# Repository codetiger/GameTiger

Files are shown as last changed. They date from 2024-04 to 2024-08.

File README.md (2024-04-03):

<p align="center">
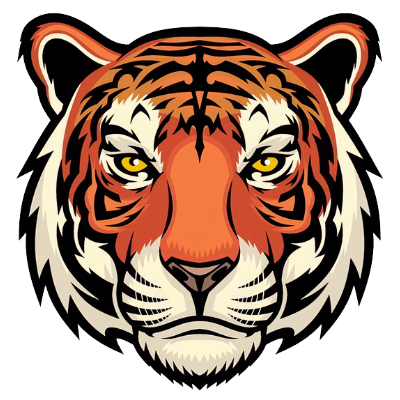
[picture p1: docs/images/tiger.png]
    
</p>
<p align="center">
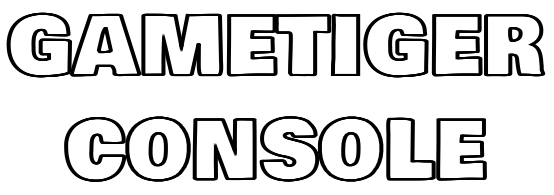
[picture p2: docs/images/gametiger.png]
    </p>
</p>

## About GameTiger Console
A retro-themed gaming console, crafted and tailored exclusively for educational enjoyment. The console boasts a custom-designed printed circuit board (PCB), meticulously created entirely from the ground up, and is centered around the remarkable RP2040 MCU chip. The primary objective of this endeavor is to maintain complete openness, facilitating the exploration of electronic PCB design and the establishment of a platform that fosters the creation of games and emulators on microcontrollers.

<div style="display: flex; justify-content: space-between;">
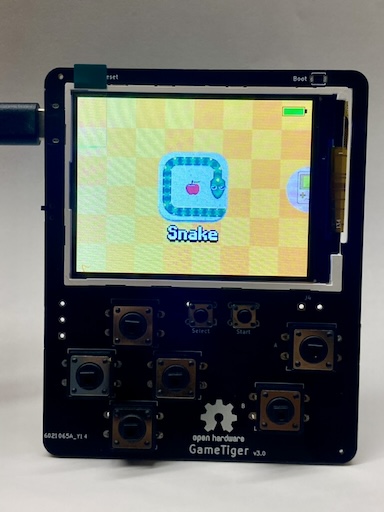
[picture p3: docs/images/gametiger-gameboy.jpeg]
GameTiger Console
    
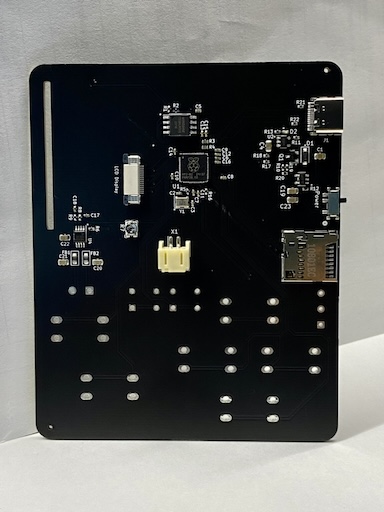
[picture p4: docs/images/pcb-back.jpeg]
    
</div>

## Games
| | |
|---|---|
| Snake | 2048 |
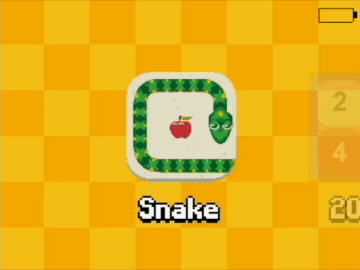
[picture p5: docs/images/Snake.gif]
Snake Game GameTiger Console
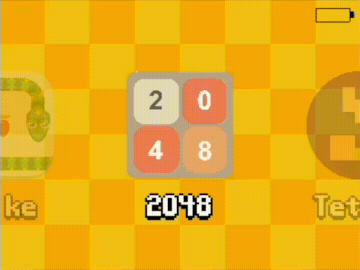
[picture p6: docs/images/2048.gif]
2048 Game GameTiger Console
|  |  
| Tetris | Minesweeper |
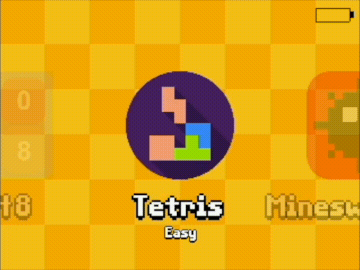
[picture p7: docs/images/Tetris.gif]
Tetris Game GameTiger Console
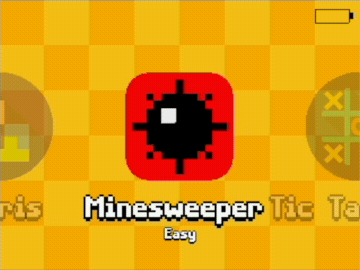
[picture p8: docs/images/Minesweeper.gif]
Minesweeper Game GameTiger Console
|  | 
| Tic Tac Toe | Ninja Frog |
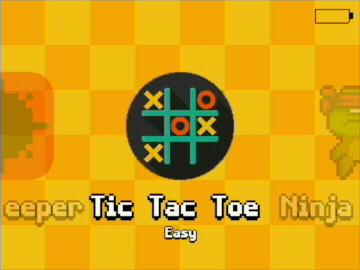
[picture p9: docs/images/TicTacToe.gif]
Tic Tac Toe Game GameTiger Console
|  | Ninja Frog Game GameTiger Console

## Software
The software is constructed using the Pico C++ SDK, incorporating essential hardware interfacing functionalities. As an illustration, the well-known Snake game is already available. The following modules are currently available and are continually being developed.

* Operating System Drivers
    * Display driver
    * Button interrupts
    * Battery management system driver
* Framebuffer Library
    * Supports transparency
    * Streaming to display memory using DMA
    * Draw primitives (Line, Rect, Fill Rect)
    * Supports drawing images with alpha channel
* Sprite sheet 
    * Support for sprite sheet 
    * Basic tilemap support
* Font system based on Sprite sheet
* Menu system
    * Games
    * Hardware config
        * Display brightness
        * Display sleep time after inactivity

The software is well optimised to achieve a target of 30 frames per second. The Snake game achieves more than 44 FPS on a default settings without overclocking. 

Hardware V3:

GameTiger Console (https://youtu.be/j1MeKHOfR0Q)

Hardware V2:

GameTiger Console (https://youtu.be/e6qAUd7l6A4)

Hardware V1:

GameTiger Console (https://youtu.be/edIZAm9zVC8)

## Build your favourite games
If you're looking to contribute to the project by developing your own games for the GameTiger console, please refer to our developer guide for detailed instructions.
[Developer's Guide](docs/dev_guide.md)

## To Do
* Add more games
* Design Case in CAD software for 3d printing

## License
The entire project is open-sourced software licensed under the MIT license.

## References
* [Hardware Design with RP2040](https://datasheets.raspberrypi.com/rp2040/hardware-design-with-rp2040.pdf)
* [Minimal RP2040 Board](http://www.technoblogy.com/show?3U75)
* [HAGL Graphics Library](https://github.com/tuupola/hagl)
* [PCB Design for RP2040 youtube video](https://www.youtube.com/watch?v=kcwvuwetgEQ)

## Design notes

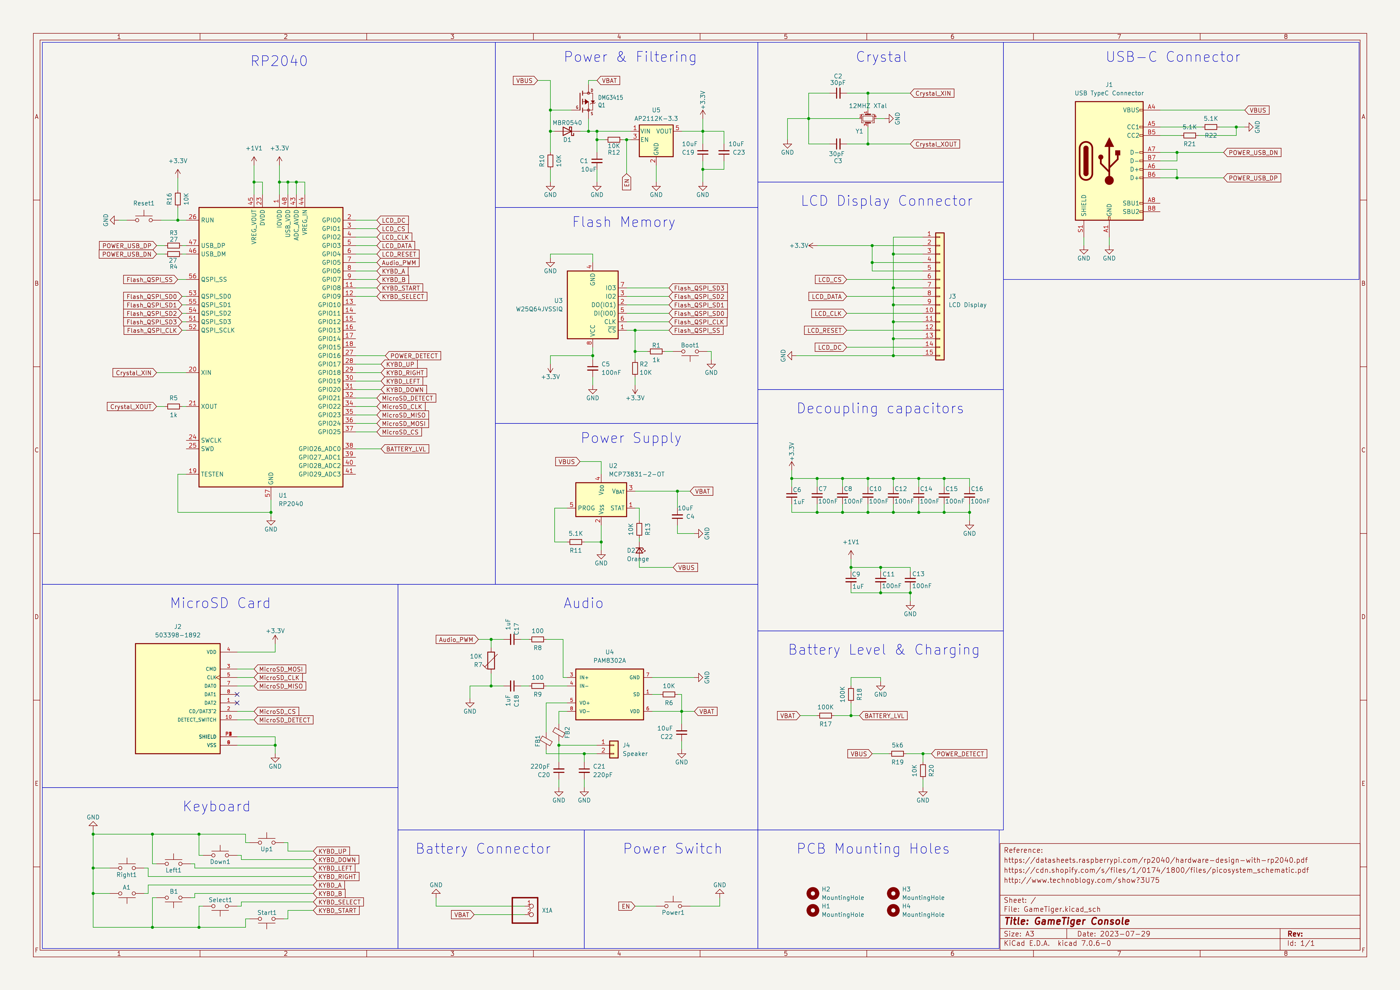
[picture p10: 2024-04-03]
PCB/GameTigerSchematic.png

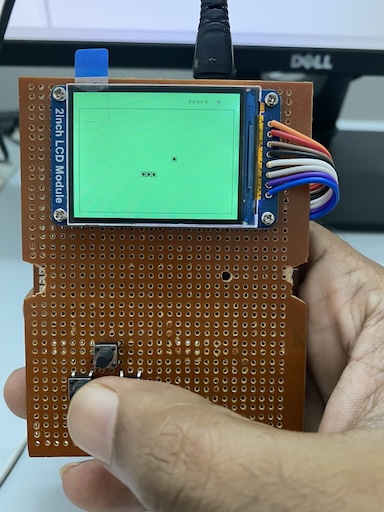
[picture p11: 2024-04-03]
docs/images/8-feb-2022.jpeg

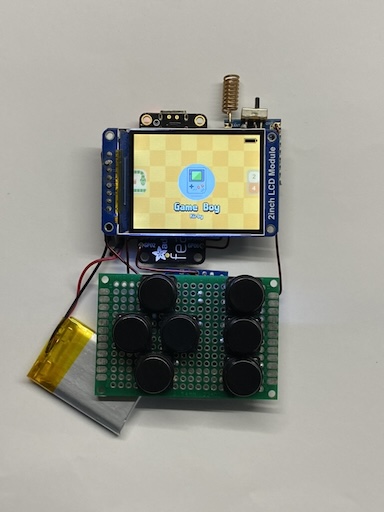
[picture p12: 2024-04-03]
docs/images/13-may-2023.jpeg

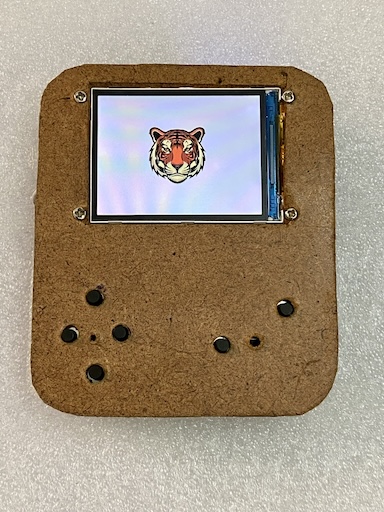
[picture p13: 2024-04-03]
docs/images/22-feb-2022.jpeg

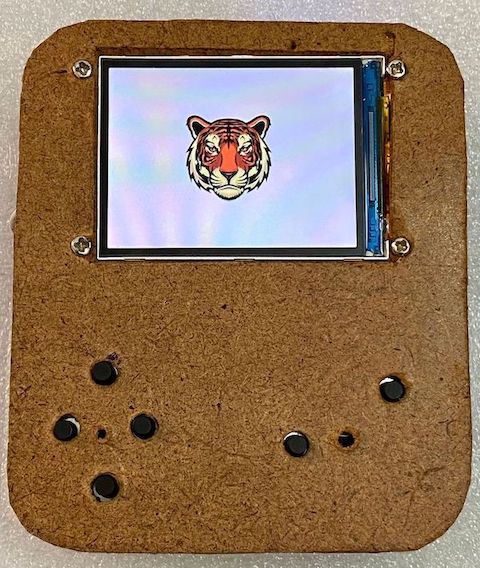
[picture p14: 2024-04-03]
docs/images/gametiger.jpg

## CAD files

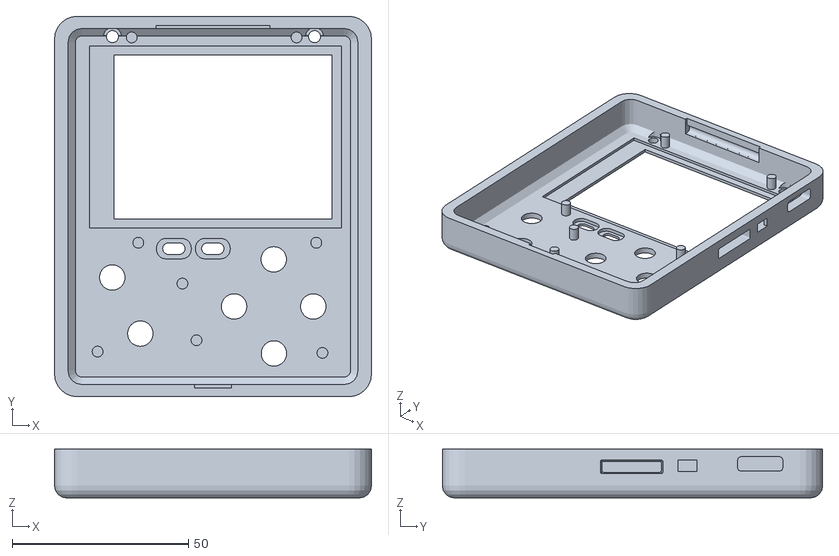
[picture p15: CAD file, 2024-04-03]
Case/GameTigerCaseFront.stl
90.0 x 108.0 x 13.9

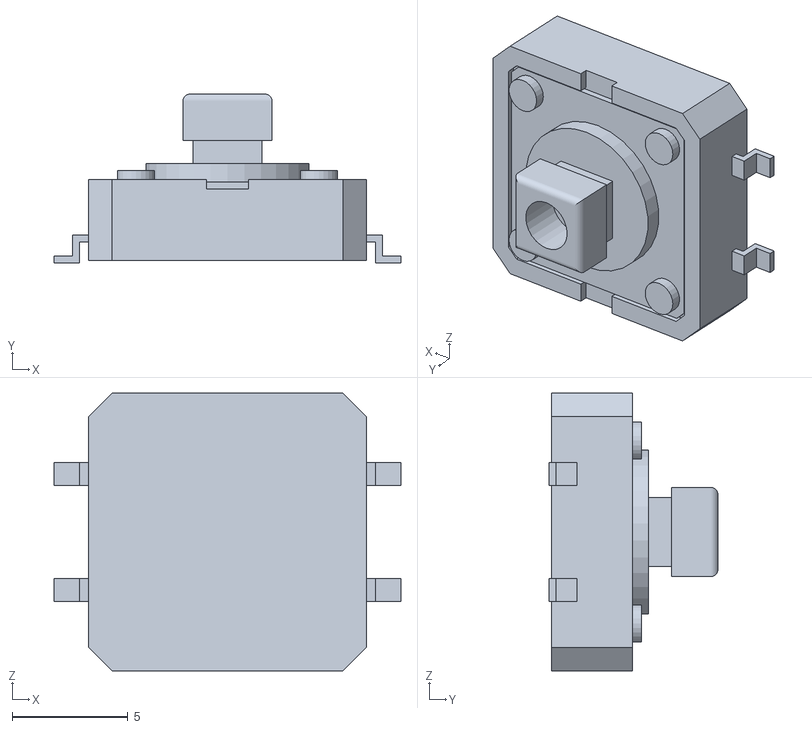
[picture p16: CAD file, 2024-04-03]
PCB/144187057-53-b3fs-4052p/b3fs-4052p.obj
15.0 x 7.30 x 12.0

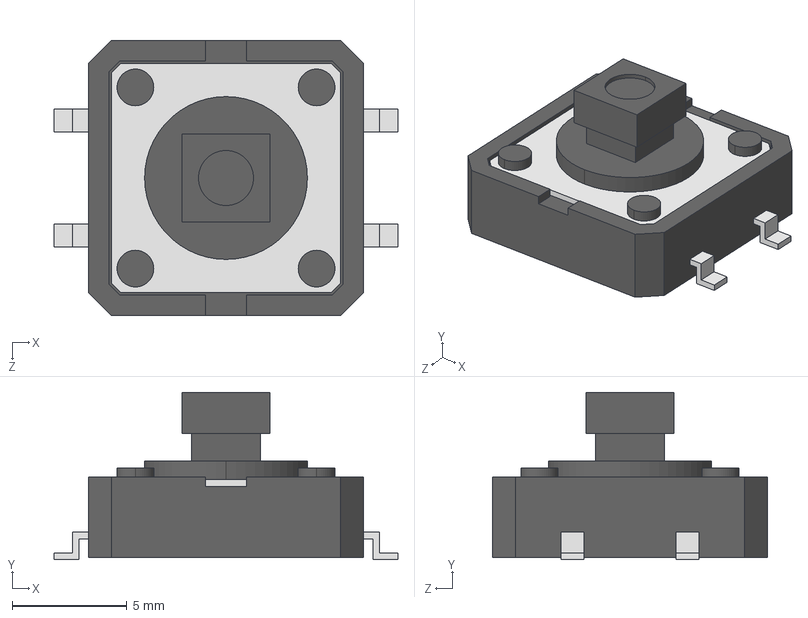
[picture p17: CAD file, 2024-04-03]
PCB/B3FS-4052P--3DModel-STEP-273799.STEP
15.0 x 7.30 x 12.0 mm

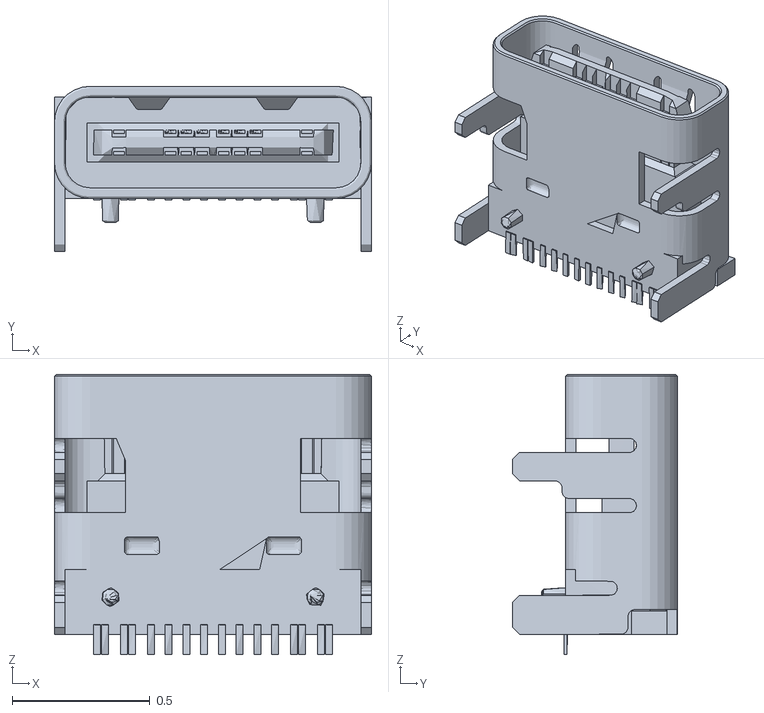
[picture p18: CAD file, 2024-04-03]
PCB/GT-USB-7010ASV/OBJ_NEW_PCB.obj
1.15 x 0.599 x 1.02

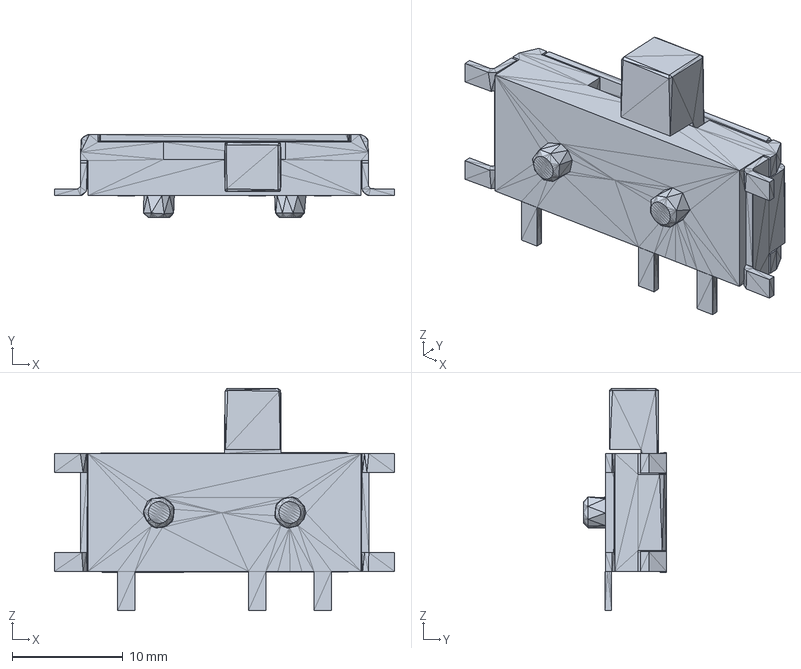
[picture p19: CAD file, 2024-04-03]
PCB/MK-12C02-G020/MK-12C02-G020.stp
30.7 x 7.48 x 20.1 mm
STEP translator 7.5 1.1
STEP translator 7.5 1.2

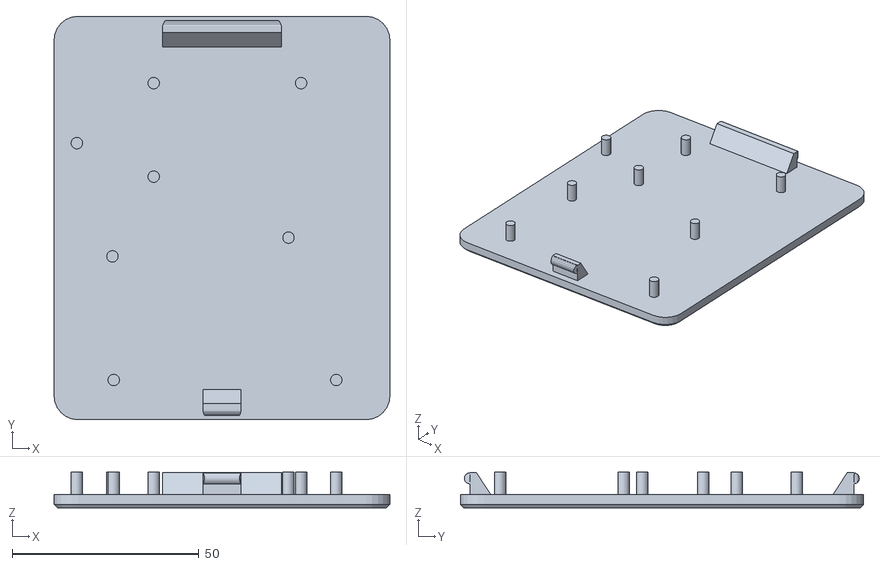
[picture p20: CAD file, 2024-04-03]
Case/GameTigerCaseBack.stl
89.9 x 108.0 x 9.52

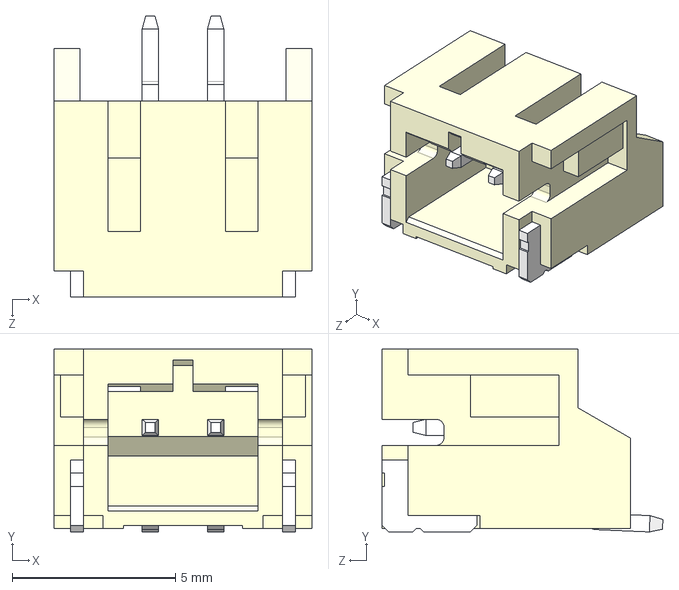
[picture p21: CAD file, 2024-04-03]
PCB/S2B-PH-SM4-TB(LF)(SN)--3DModel-STEP-56544.STEP
7.90 x 5.60 x 8.60 mm

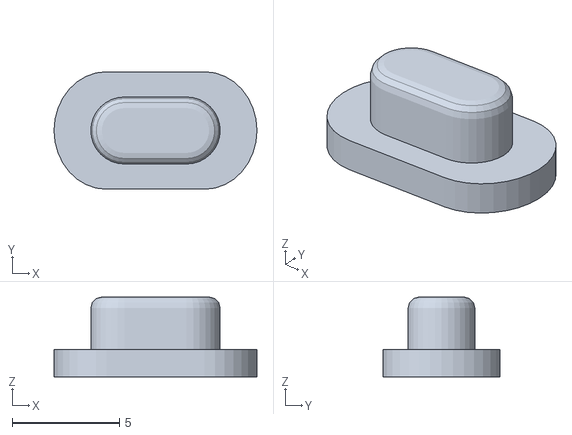
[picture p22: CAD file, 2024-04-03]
Case/GameTigerButtonSelect.stl
9.45 x 5.47 x 3.72

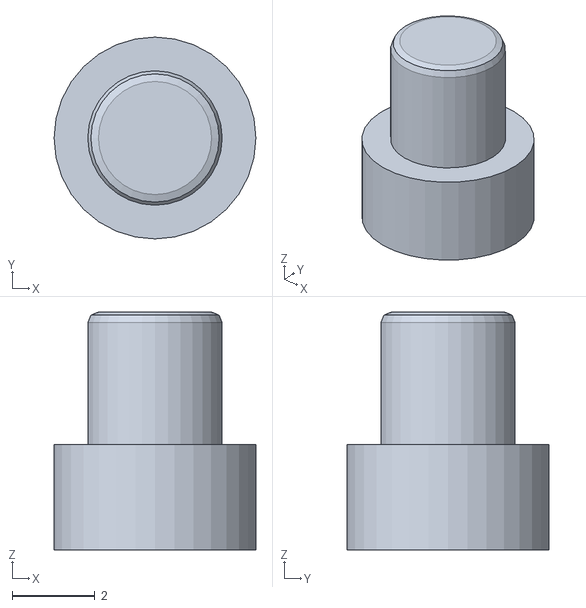
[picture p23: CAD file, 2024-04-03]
Case/GameTigerButtonBoot.stl
4.88 x 4.88 x 5.76

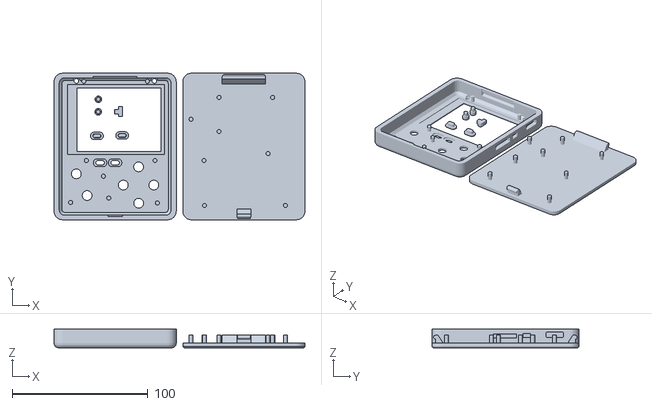
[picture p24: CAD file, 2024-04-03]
Case/GameTigerCase.stl
184.7 x 108.0 x 13.9

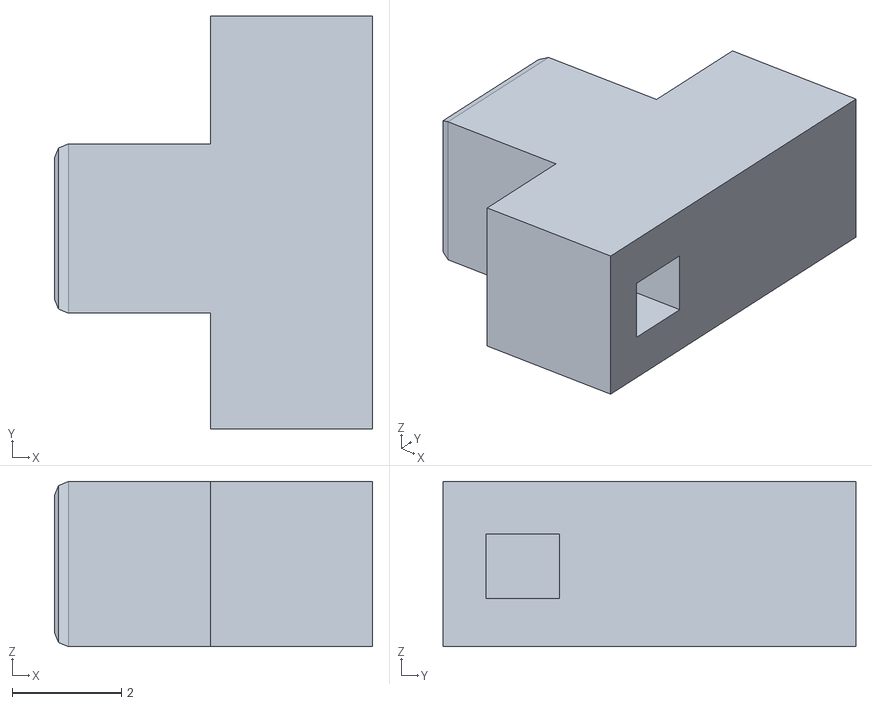
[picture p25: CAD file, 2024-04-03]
Case/GameTigerButtonPower.stl
5.82 x 7.55 x 3.02

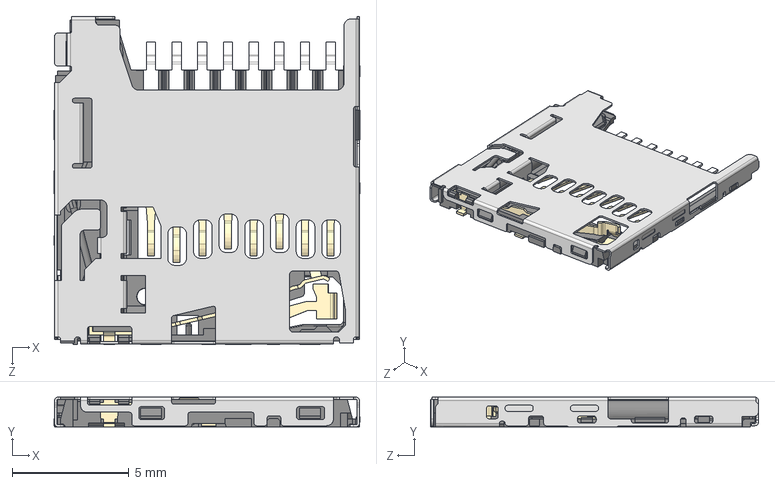
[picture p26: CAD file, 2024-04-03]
PCB/503398-1892/503398-1892.step
13.1 x 1.28 x 14.1 mm

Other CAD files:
Case/GameTigerButtonReset.stl
Case/GameTigerButtonStart.stl
Case/GameTigerCase.blend
PCB/GT-USB-7010ASV/GT-USB-7010ASV.blend

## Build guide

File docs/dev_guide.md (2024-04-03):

# Developer's Guide

This page contains details on setting up the development environment  for writing your own software for GameTiger console

## Building the firmware

First install required packages
```bash
sudo apt-get update
sudo apt-get install  git cmake build-essential gcc-arm-none-eabi libnewlib-arm-none-eabi libstdc++-arm-none-eabi-newlib
```

Clone the main repo
```bash
git clone https://github.com/codetiger/GameTiger-Console
```

Clone *pico-sdk* and *pico-extras* repository, since we will need them for compiling our code

```bash
git clone -b master --recurse-submodules https://github.com/codetiger/pico-sdk
git clone -b master --recurse-submodules https://github.com/raspberrypi/pico-extras
```

Set required environment variables (make sure to use proper paths depending upon your setup)

```bash
export PICO_SDK_PATH=/workspace/pico-sdk
export PICO_TOOLCHAIN_PATH=/usr
export PICO_EXTRAS_PATH=/workspace/pico-extras
```

Now let us compile the software for GameTiger console

```bash
cd GameTiger-Console
cmake .
make
```

On successful completion, you should see something similar to below output:

```bash
[ 97%] Performing build step for 'PioasmBuild'
[ 10%] Building CXX object CMakeFiles/pioasm.dir/main.cpp.o
[ 20%] Building CXX object CMakeFiles/pioasm.dir/pio_assembler.cpp.o
[ 30%] Building CXX object CMakeFiles/pioasm.dir/pio_disassembler.cpp.o
[ 40%] Building CXX object CMakeFiles/pioasm.dir/gen/lexer.cpp.o
[ 50%] Building CXX object CMakeFiles/pioasm.dir/gen/parser.cpp.o
[ 60%] Building CXX object CMakeFiles/pioasm.dir/c_sdk_output.cpp.o
[ 70%] Building CXX object CMakeFiles/pioasm.dir/python_output.cpp.o
[ 80%] Building CXX object CMakeFiles/pioasm.dir/hex_output.cpp.o
[ 90%] Building CXX object CMakeFiles/pioasm.dir/ada_output.cpp.o
[100%] Linking CXX executable pioasm
[100%] Built target pioasm
[ 98%] No install step for 'PioasmBuild'
[100%] Completed 'PioasmBuild'
[100%] Built target PioasmBuild
```

Once the compilation is successful, a firmware file called '*GameTiger.uf2*' should be generated in the '*GameTiger-Console*' folder.
Power on the console by holding the *boot* button and copy the '*GameTiger.uf2*' to the device.

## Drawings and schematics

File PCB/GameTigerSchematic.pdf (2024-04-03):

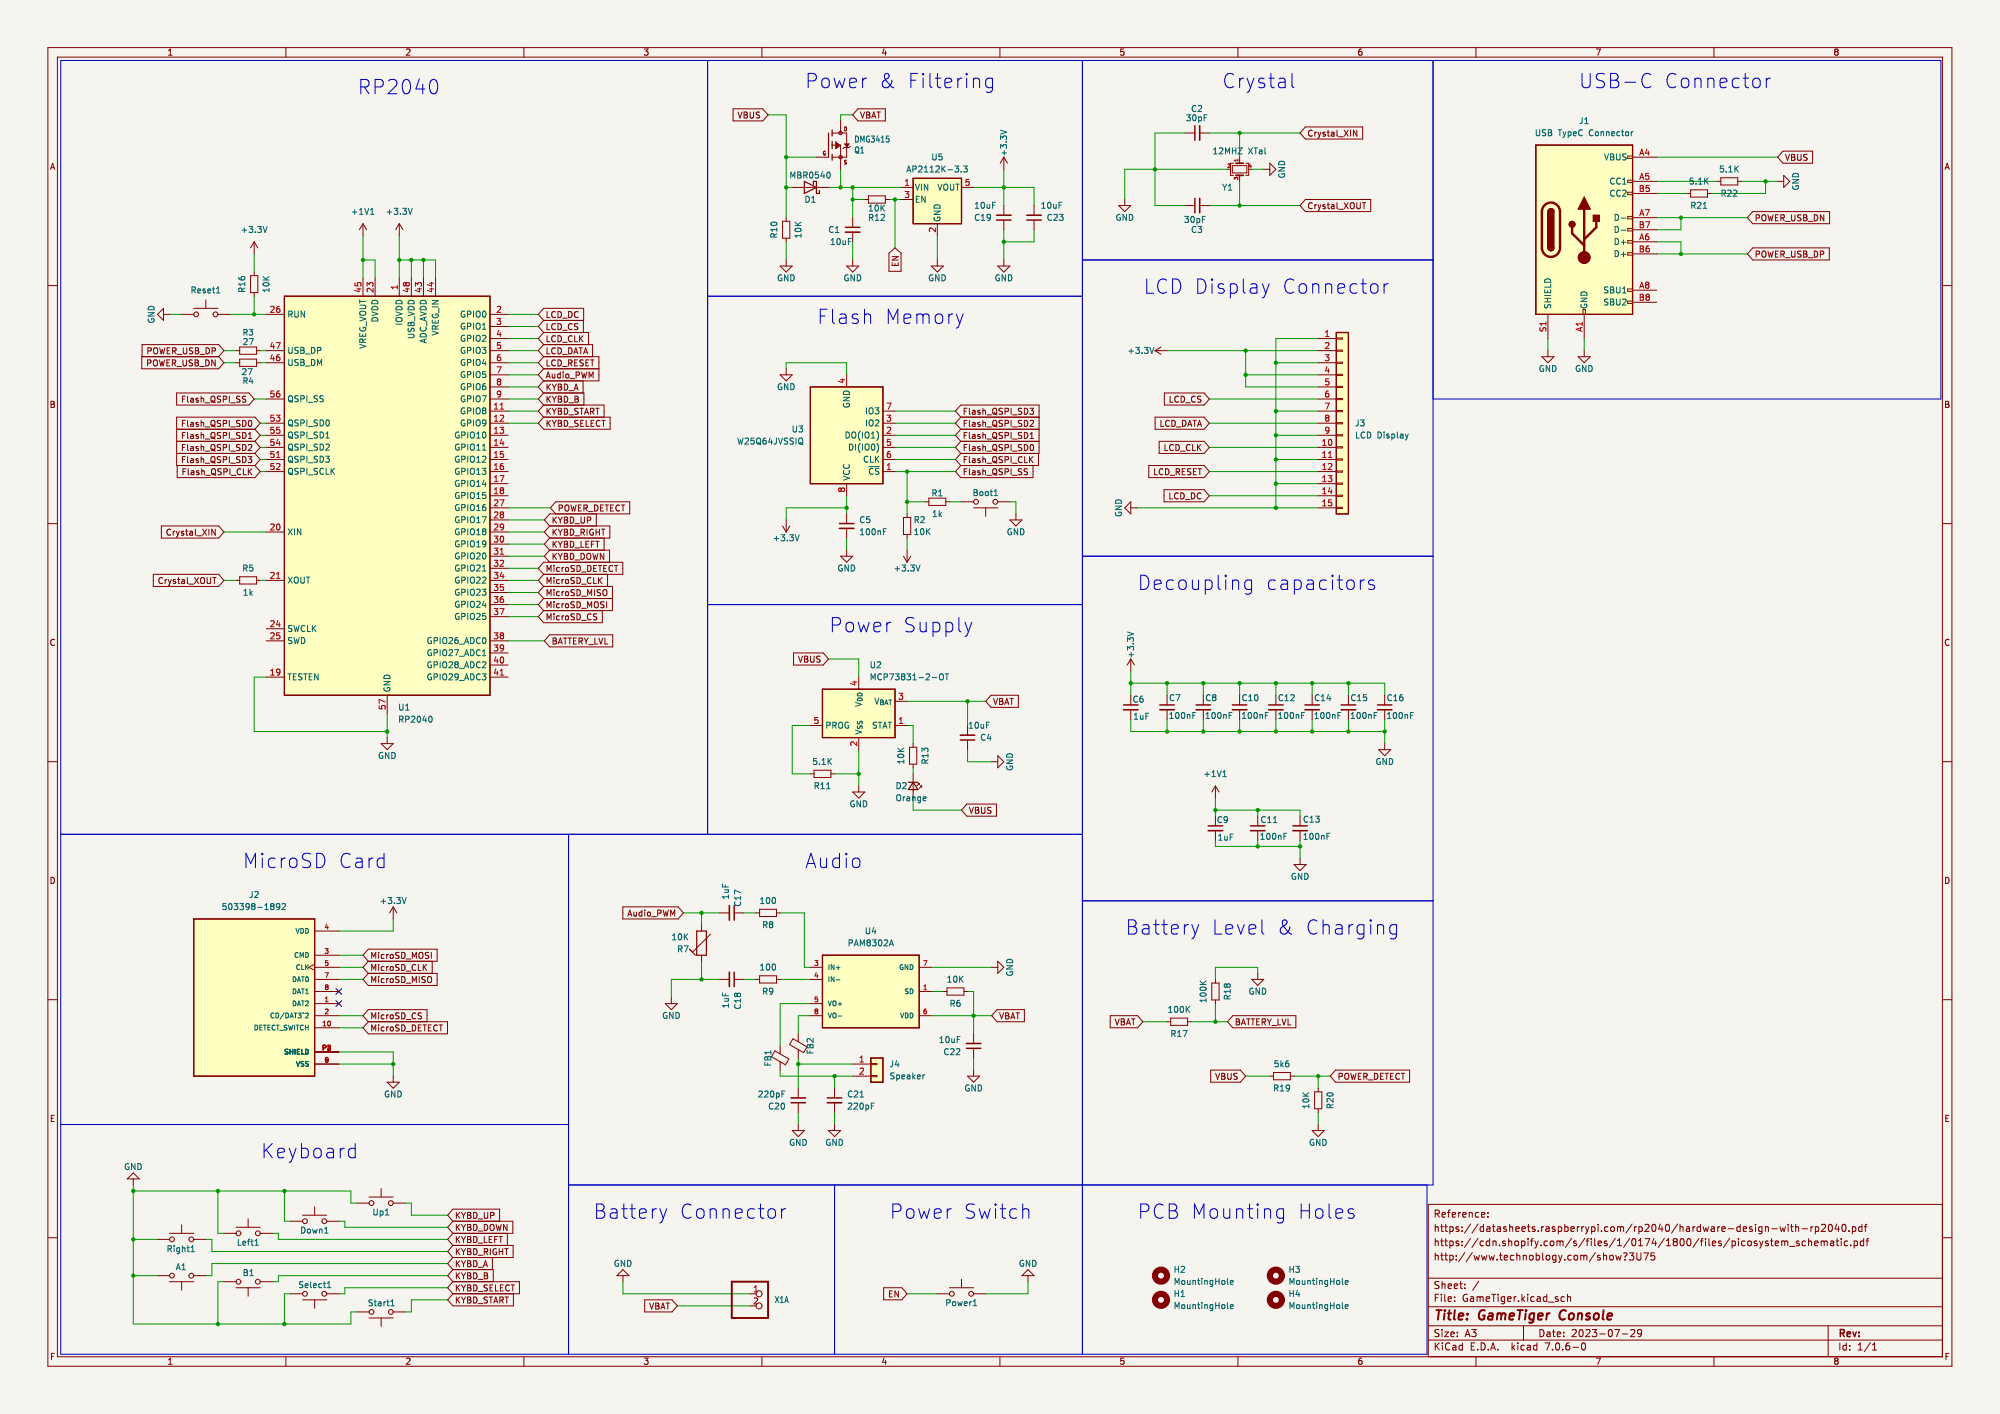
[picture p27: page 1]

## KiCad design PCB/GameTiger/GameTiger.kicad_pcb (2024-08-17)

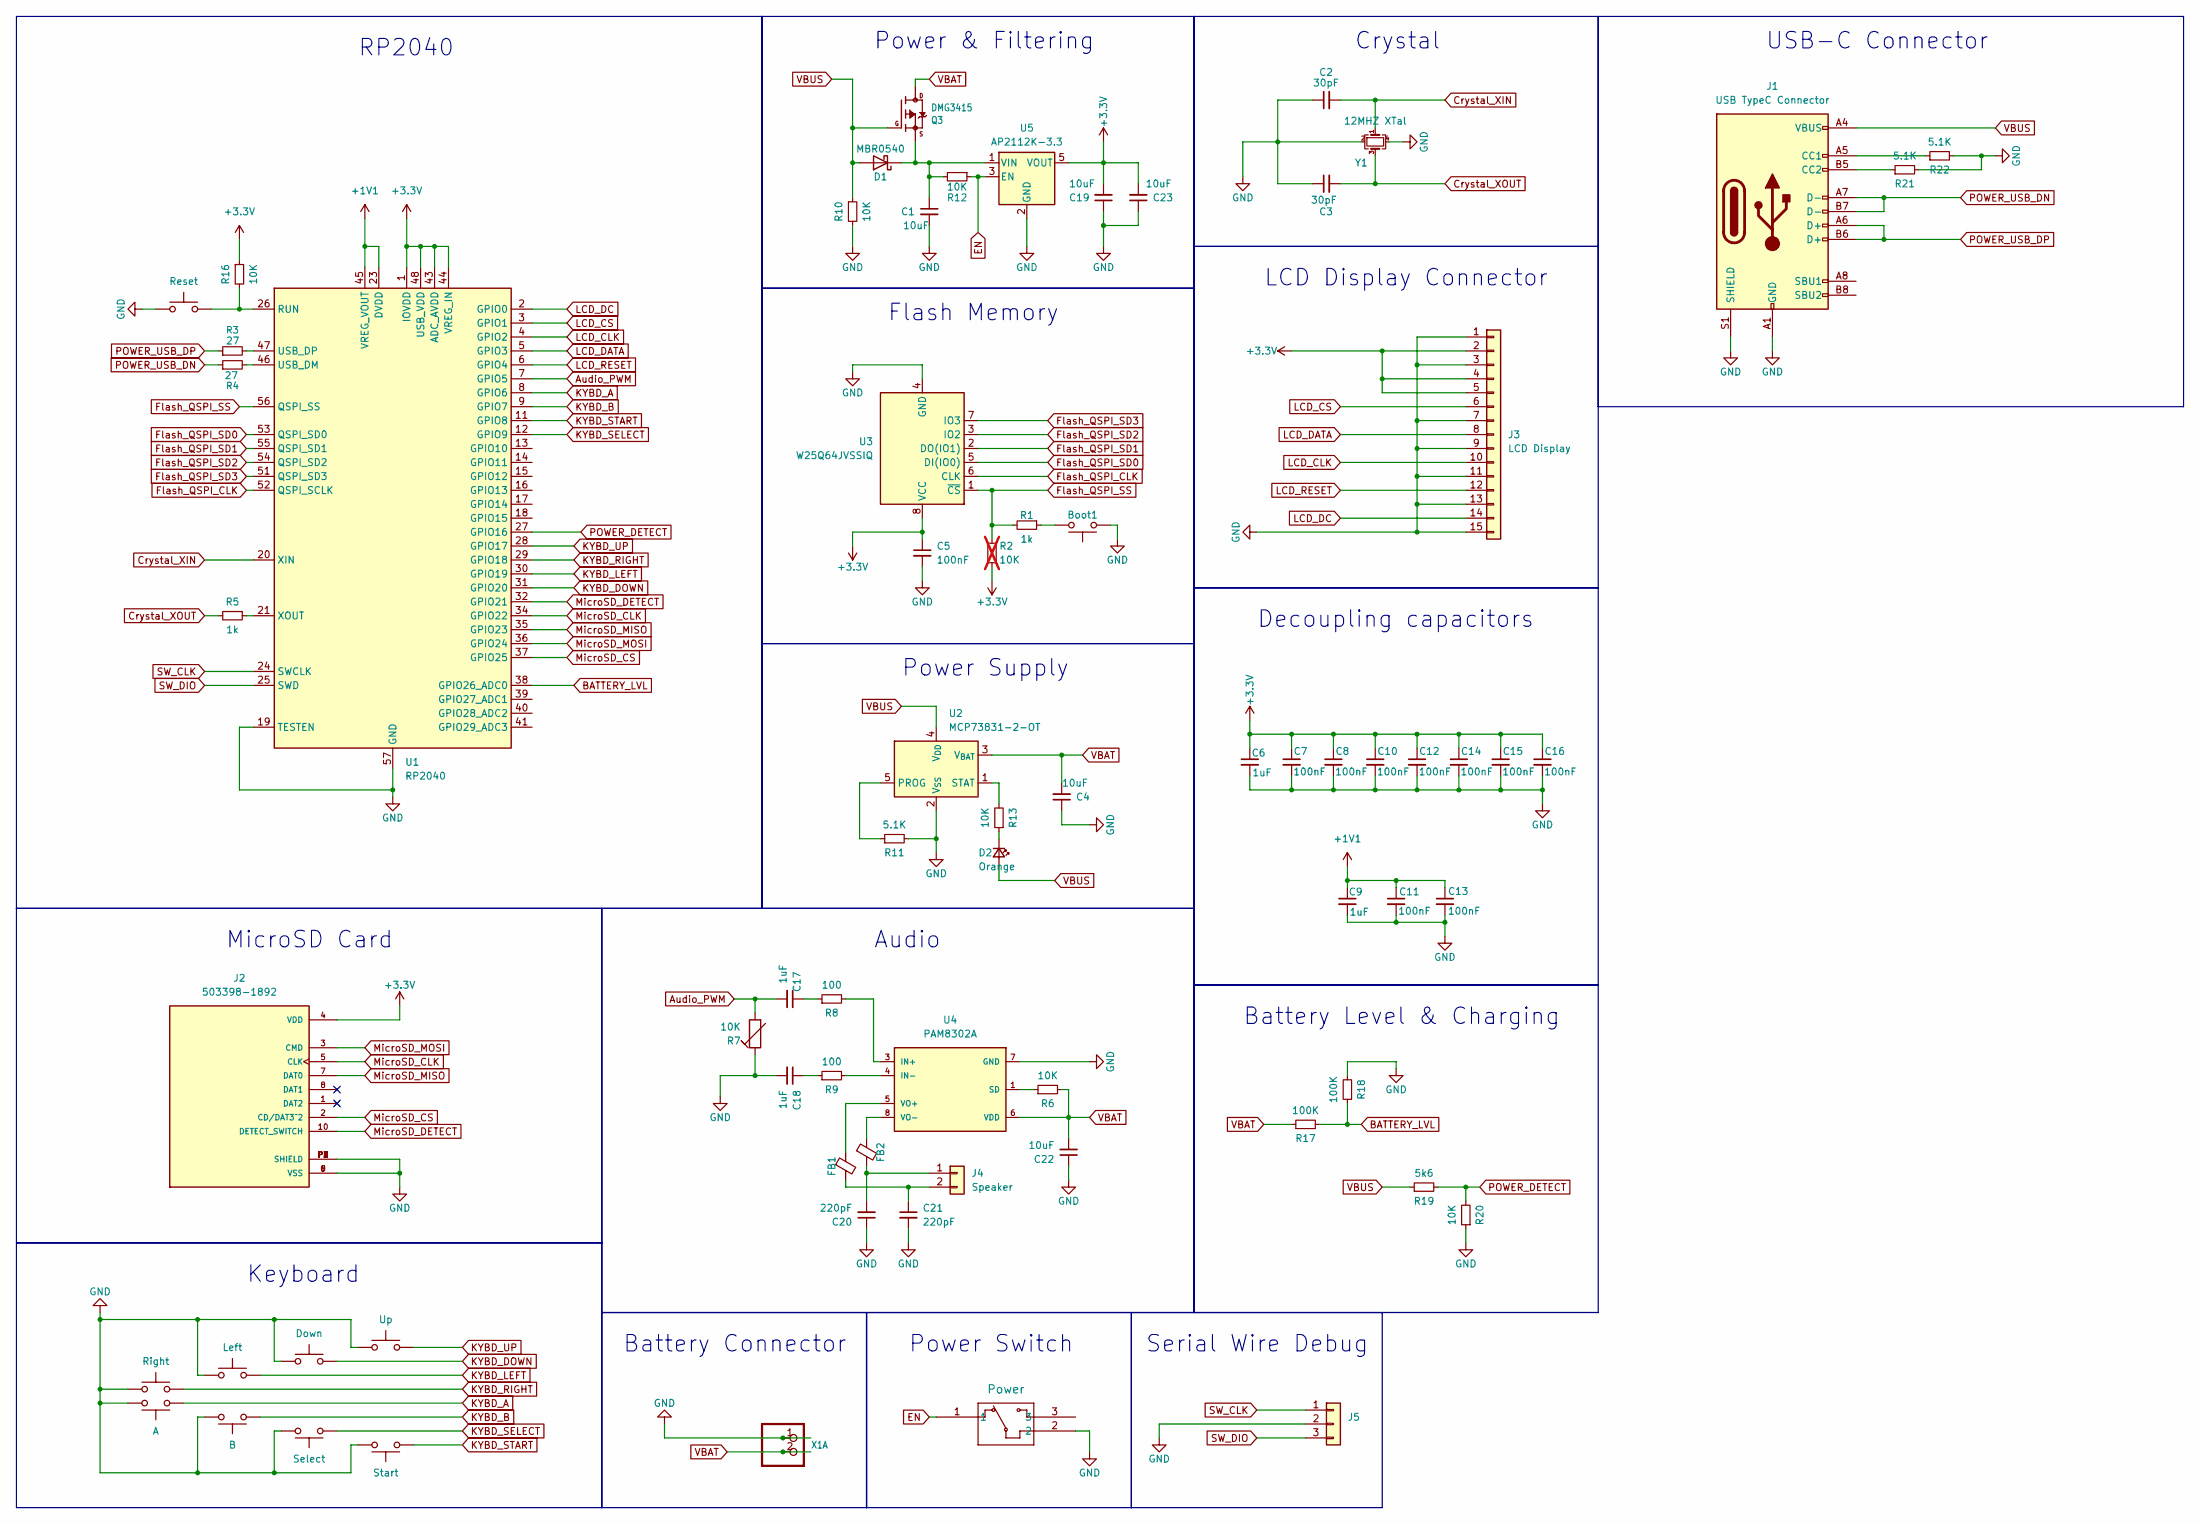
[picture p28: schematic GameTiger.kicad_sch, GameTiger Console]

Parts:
A1: A; SW_PUSH-12mm_3DModel; LCSC C411882
B1: B; SW_PUSH-12mm_3DModel; LCSC C411882
Boot1: Boot; SW_SPST_B3U-1000P; Mfr.Part # B3U-1000P; LCSC C231329
C1, C4, C19, C22, C23: 10uF; C_0805_2012Metric; LCSC C15850
C2, C3: 30pF; C_0402_1005Metric; LCSC C1570
C5, C7, C8, C10, C11, C12, C13, C14, C15, C16: 100nF; C_0402_1005Metric; LCSC C1525
C6, C9, C17, C18: 1uF; C_0402_1005Metric; LCSC C52923
C20, C21: 220pF; C_0805_2012Metric; LCSC C107145
D1: MBR0540; D_SOD-123; Manuf. Part # MBR0540; LCSC C116159
D2: Orange; LED_0402_1005Metric; LCSC C965791
Down1: Down; SW_PUSH-12mm_3DModel; LCSC C411882
FB1, FB2: FerriteBead_Small; Ferrite_0805_2012Metric; Manuf. Part # BLM21BD102SN1D; LCSC C85835
J1: USB TypeC Connector; USB_C_Receptacle_HRO_TYPE-C-31-M-12; Manuf. Part # GT-USB-7010ASV; LCSC C2988369
J2: 503398-1892; MOLEX_503398-1892; Manuf. Part # 5033981892; LCSC C428492
J3: LCD Display; TE_1-1734839-5_1x15-1MP_P0.5mm_Horizontal; Manuf. Part # 1-1734839-5; LCSC C262209
J4: Speaker; SolderWire-0.5sqmm_1x02_P4.6mm_D0.9mm_OD2.1mm
J5: Conn_01x03; SolderWire-0.25sqmm_1x03_P4.2mm_D0.65mm_OD1.7mm
Left1: Left; SW_PUSH-12mm_3DModel; LCSC C411882
Power1: Power; MK-12C02-G020_GSW; Manuf. Part # MK-12C02-G020; LCSC C963206
Q3: DMG3415; SOT-23; Manuf. Part # DMG3415U-7; LCSC C96616
R1, R5: 1k; R_0402_1005Metric; LCSC C11702
R2: 10K; R_0402_1005Metric; LCSC C25744; not fitted
R3, R4: 27; R_0402_1005Metric; LCSC C25190
R6, R10, R12, R13, R16, R20: 10K; R_0402_1005Metric; LCSC C25744
R7: 10K; Potentiometer_Bourns_TC33X_Vertical; Manuf. Part # TC33X-2-103E; LCSC C719176
R8, R9: 100; R_0402_1005Metric; LCSC C25076
R11, R21, R22: 5.1K; R_0402_1005Metric; LCSC C25905
R17, R18: 100K; R_0402_1005Metric; LCSC C25741
R19: 5k6; R_0402_1005Metric; LCSC C25908
Reset1: Reset; SW_SPST_B3U-1000P; Mfr.Part # B3U-1000P; LCSC C231329
Right1: Right; SW_PUSH-12mm_3DModel; LCSC C411882
Select1: Select; SW_TH_Tactile_Omron_B3F-10xx; LCSC C411882
Start1: Start; SW_TH_Tactile_Omron_B3F-10xx; LCSC C411882
U1: RP2040; QFN-56-1EP_7x7mm_P0.4mm_EP3.2x3.2mm; Mfr.Part # RP2040; LCSC C2040
U2: MCP73831-2-OT; SOT-23-5; Manuf. Part # MCP73831T-2ACI/OT; LCSC C424093
U3: W25Q64JVSSIQ; SOIC-8_5.23x5.23mm_P1.27mm; Manuf. Part # W25Q64JVSSIQ; LCSC C179171
U4: PAM8302A; MSOP-8_3x3mm_P0.65mm; Manuf. Part # PAM8302AASCR; LCSC C113367
U5: AP2112K-3.3; SOT_RG1_DIO; Manuf. Part # AP2112K-3.3TRG1; LCSC C51118
Up1: Up; SW_PUSH-12mm_3DModel; LCSC C411882
X1: JST_PH_S2B-PH-SM4-TB_1x02-1MP_P2.00mm_Horizontal; Manuf. Part # S2B-PH-SM4-TB(LF)(SN); LCSC C295747
Y1: 12MHZ XTal; Crystal_SMD_3225-4Pin_3.2x2.5mm; Manuf. Part # X322512MSB4SI; LCSC C9002

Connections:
+1V1: C9.1, C11.1, C13.1, U1.23 (DVDD), U1.45 (VREG_VOUT), U1.50 (DVDD)
+3.3V: C5.1, C6.1, C7.1, C8.1, C10.1, C12.1, C14.1, C15.1, C16.1, C19.2, C23.2, J2.4 (VDD), J3.2, J3.4, J3.5, R2.1, R16.1, U1.1 (IOVDD), U1.10 (IOVDD), U1.22 (IOVDD), U1.33 (IOVDD), U1.42 (IOVDD), U1.43 (ADC_AVDD), U1.44 (VREG_IN), U1.48 (USB_VDD), U1.49 (IOVDD), U3.8 (VCC), U5.5 (VOUT)
Audio_PWM: C17.2, R7.2, U1.7 (GPIO5)
BATTERY_LVL: R17.2, R18.1, U1.38 (GPIO26_ADC0)
Crystal_XIN: C2.2, U1.20 (XIN), Y1.1
Crystal_XOUT: C3.2, R5.2, Y1.3
EN: Power1.1, R12.1, U5.3 (EN)
Flash_QSPI_CLK: U1.52 (QSPI_SCLK), U3.6 (CLK)
Flash_QSPI_SD0: U1.53 (QSPI_SD0), U3.5 (DI(IO0))
Flash_QSPI_SD1: U1.55 (QSPI_SD1), U3.2 (DO(IO1))
Flash_QSPI_SD2: U1.54 (QSPI_SD2), U3.3 (IO2)
Flash_QSPI_SD3: U1.51 (QSPI_SD3), U3.7 (IO3)
Flash_QSPI_SS: R1.2, R2.2, U1.56 (QSPI_SS), U3.1 (~CS)
GND: A1.2, B1.2, Boot1.1, C1.2, C2.1, C3.1, C4.1, C5.2, C6.2, C7.2, C8.2, C9.2, C10.2, C11.2, C12.2, C13.2, C14.2, C15.2, C16.2, C18.2, C19.1, C20.1, C21.2, C22.1, C23.1, Down1.1, J1.A1 (GND), J1.A12 (GND), J1.B1 (GND), J1.B12 (GND), J1.S1 (SHIELD), J2.6 (VSS), J2.9 (VSS), J2.P1 (SHIELD), J2.P2 (SHIELD), J2.P3 (SHIELD), J2.P4 (SHIELD), J3.1, J3.3, J3.7, J3.9, J3.11, J3.13, J3.15, J5.2, Left1.1, Power1.2, R7.1, R10.2, R11.2, R18.2, R20.1, R21.2, R22.2, Reset1.1, Right1.1, Select1.2, Start1.2, U1.19 (TESTEN), U1.57 (GND), U2.2 (V_{SS}), U3.4 (GND), U4.7 (GND), U5.2 (GND), Up1.1, X1.1, Y1.2, Y1.4
KYBD_A: A1.1, U1.8 (GPIO6)
KYBD_B: B1.1, U1.9 (GPIO7)
KYBD_DOWN: Down1.2, U1.31 (GPIO20)
KYBD_LEFT: Left1.2, U1.30 (GPIO19)
KYBD_RIGHT: Right1.2, U1.29 (GPIO18)
KYBD_SELECT: Select1.1, U1.12 (GPIO9)
KYBD_START: Start1.1, U1.11 (GPIO8)
KYBD_UP: U1.28 (GPIO17), Up1.2
LCD_CLK: J3.10, U1.4 (GPIO2)
LCD_CS: J3.6, U1.3 (GPIO1)
LCD_DATA: J3.8, U1.5 (GPIO3)
LCD_DC: J3.14, U1.2 (GPIO0)
LCD_RESET: J3.12, U1.6 (GPIO4)
MicroSD_CLK: J2.5 (CLK), U1.34 (GPIO22)
MicroSD_CS: J2.2 (CD/DAT3^2), U1.37 (GPIO25)
MicroSD_DETECT: J2.10 (DETECT_SWITCH), U1.32 (GPIO21)
MicroSD_MISO: J2.7 (DAT0), U1.35 (GPIO23)
MicroSD_MOSI: J2.3 (CMD), U1.36 (GPIO24)
unnamed: Boot1.2, R1.1
unnamed: C17.1, R8.1
unnamed: C18.1, R9.1
unnamed 35: C1.1, D1.1 (K), R12.2, U5.1 (VIN); also elsewhere on the board
unnamed: D2.1 (K), R13.1
unnamed: J1.A5 (CC1), R22.1
unnamed: J1.B5 (CC2), R21.1
unnamed: C20.2, FB2.2, J4.1
unnamed: C21.1, FB1.2, J4.2
unnamed: R16.2, Reset1.2, U1.26 (RUN)
unnamed: R4.2, U1.46 (USB_DM)
unnamed: R3.2, U1.47 (USB_DP)
unnamed: R5.1, U1.21 (XOUT)
unnamed: R11.1, U2.5 (PROG)
unnamed: R13.2, U2.1 (STAT)
unnamed: R8.2, U4.3 (IN+)
unnamed: R9.2, U4.4 (IN-)
unnamed: R6.1, U4.1 (SD)
unnamed: FB1.1, U4.5 (VO+)
unnamed: FB2.1, U4.8 (VO-)
POWER_DETECT: R19.2, R20.2, U1.27 (GPIO16)
POWER_USB_DN: J1.A7 (D-), J1.B7 (D-), R4.1
POWER_USB_DP: J1.A6 (D+), J1.B6 (D+), R3.1
SW_CLK: J5.1, U1.24 (SWCLK)
SW_DIO: J5.3, U1.25 (SWD)
VBAT: C4.2, C22.2, R6.2, R17.1, U2.3 (V_{BAT}), U4.6 (VDD), X1.2; also elsewhere on the board
VBUS: D1.2 (A), D2.2 (A), J1.A4 (VBUS), J1.A9 (VBUS), J1.B4 (VBUS), J1.B9 (VBUS), R10.1, R19.1, U2.4 (V_{DD}); also elsewhere on the board

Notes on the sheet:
Serial Wire Debug
Battery Connector
Audio
Battery Level & Charging
RP2040
Power Switch
Keyboard
Decoupling capacitors
MicroSD Card
Power Supply
LCD Display Connector
Power & Filtering
Crystal
Flash Memory
USB-C Connector

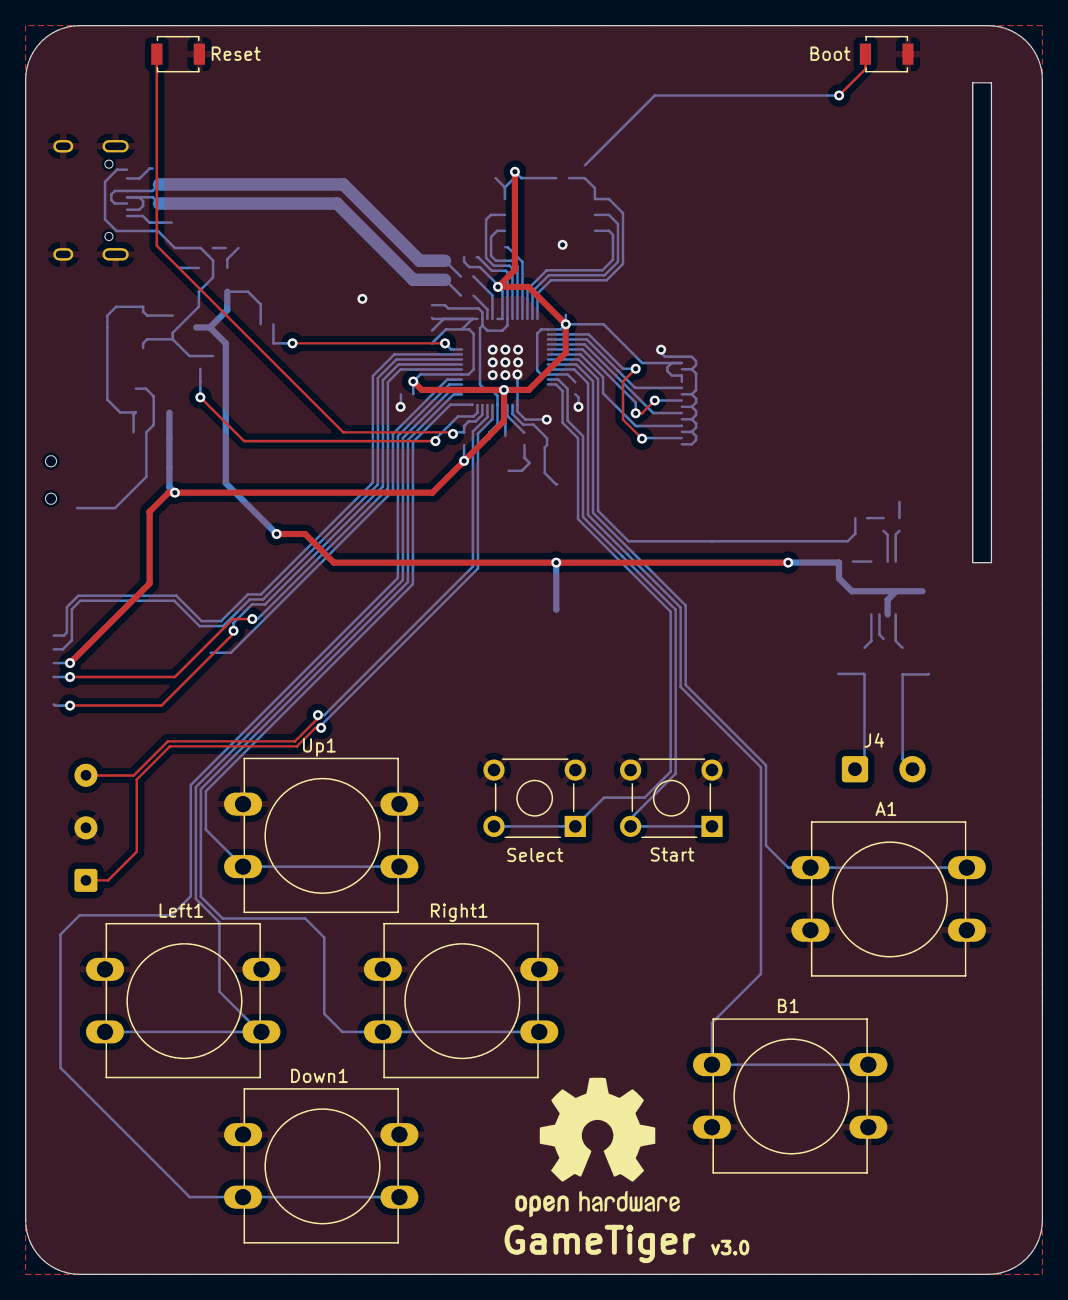
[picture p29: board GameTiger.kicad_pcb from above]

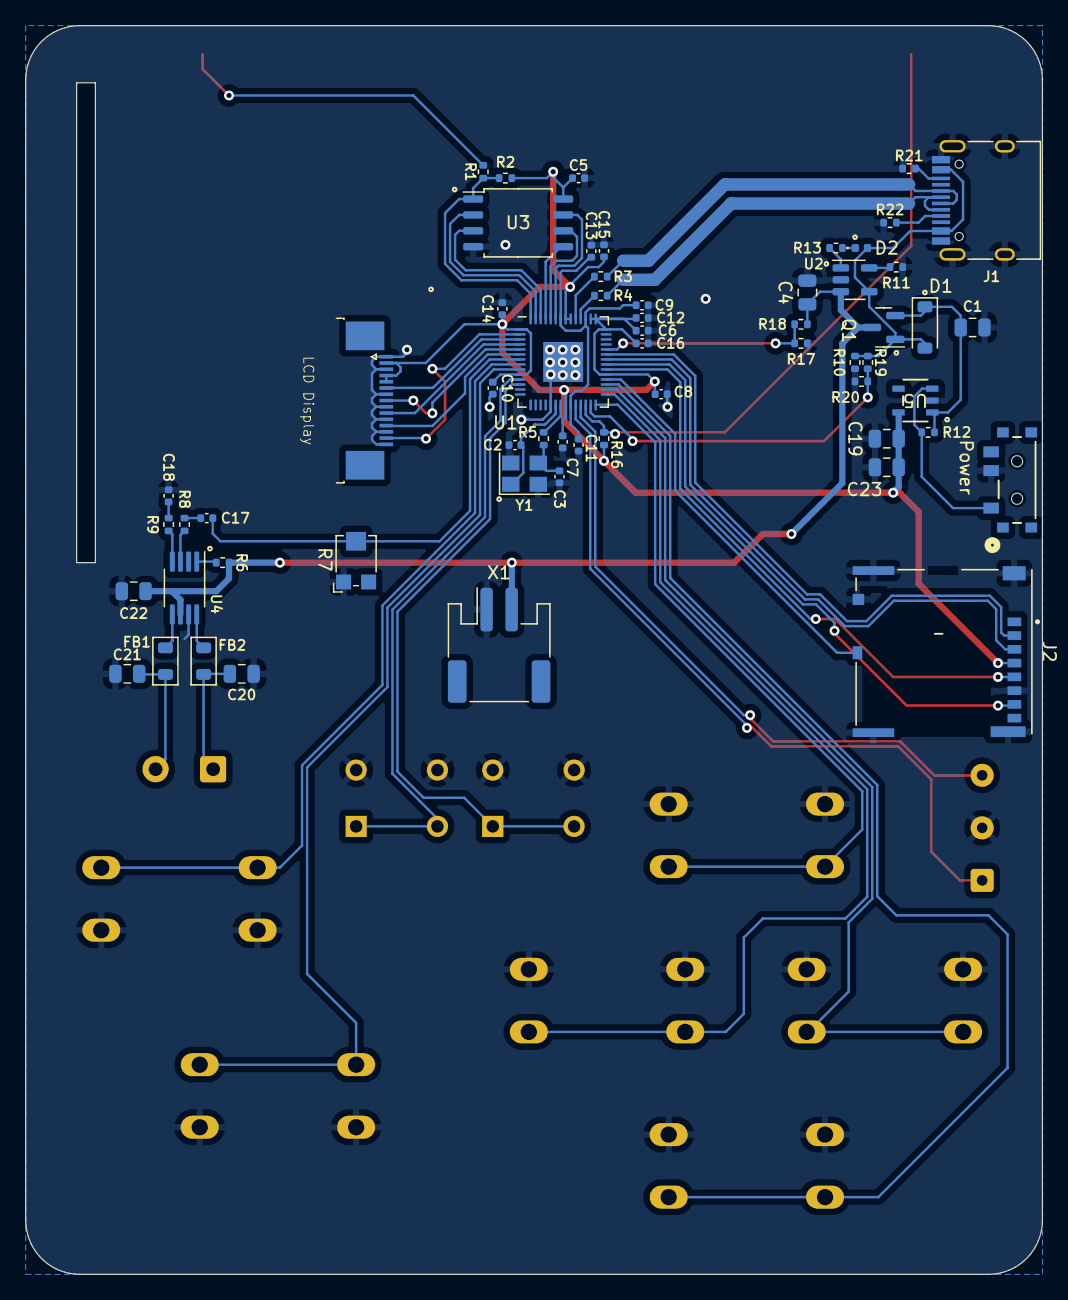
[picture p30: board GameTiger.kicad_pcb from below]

Board: 2 copper layers, 81.3 x 99.8 mm, 71 parts (59 on the bottom side), 59 nets.

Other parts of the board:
Q1: DMG3415; SOT-23

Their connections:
unnamed 35: Q1.2 (S); also elsewhere on the board
VBAT: Q1.3 (D); also elsewhere on the board
VBUS: Q1.1 (G); also elsewhere on the board

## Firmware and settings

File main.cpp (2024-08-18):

#include "core/common.h"
#include "core/display.h"
#include "core/battery.h"
#include "core/keyboard.h"
#include "core/LoRa/lora.h"

#include "screens/splashscreen.h"
#include "screens/menuscreen.h"
#include "screens/snakescreen.h"
#include "screens/gameboyscreen.h"
#include "screens/g2048screen.h"
#include "screens/tetrisscreen.h"
#include "screens/minescreen.h"
#include "screens/ticscreen.h"
#include "screens/pa2screen.h"
#include "screens/aboutscreen.h"
#include "screens/settingsscreen.h"

#define HIGHSCORESIZE (FLASH_PAGE_SIZE/4)
#define FLASH_TARGET_OFFSET (1536 * 1024)

Screen *screen;
Lora *lora;
uint32_t highscores[64];
bool shouldSwitchScreen;
uint8_t newScreenId, newOption;

void highScoreHandler(uint32_t highscore) {
    highscores[0] = 64;highscores[1] = 128;
    highscores[screen->screenId] = highscore;
    uint32_t ints = save_and_disable_interrupts();
    flash_range_erase(FLASH_TARGET_OFFSET, FLASH_SECTOR_SIZE);
    flash_range_program(FLASH_TARGET_OFFSET, (uint8_t*)highscores, FLASH_PAGE_SIZE);
    restore_interrupts (ints);
}

void readHighScoreData() {
    const uint32_t* flash_target_contents = (const uint32_t *) (XIP_BASE + FLASH_TARGET_OFFSET);
    for (int i = 0; i < HIGHSCORESIZE; i++)
        highscores[i] = flash_target_contents[i];
    if(highscores[0] != 64 || highscores[1] != 128)
        for (int i = 0; i < HIGHSCORESIZE; i++)
            highscores[i] = 0;
}

void backHandler(int8_t menu, uint8_t option) {
    newScreenId = menu;
    newOption = option;
    shouldSwitchScreen = true;
}

void checkScreenSwitch() {
    if(!shouldSwitchScreen)
        return;

    if(screen->screenId == ScreenEnum::MENUSCREEN) {
        delete screen;
        if(newScreenId == ScreenEnum::SNAKESCREEN)
            screen = new SnakeScreen(*backHandler, *highScoreHandler, highscores[newScreenId], newOption);
        else if(newScreenId == ScreenEnum::GAMEBOYSCREEN)
            screen = new GameBoyScreen(*backHandler, *highScoreHandler, highscores[newScreenId], newOption);
        else if(newScreenId == ScreenEnum::G2048SCREEN)
            screen = new G2048Screen(*backHandler, *highScoreHandler, highscores[newScreenId], newOption);
        else if(newScreenId == ScreenEnum::TETRISSCREEN)
            screen = new TetrisScreen(*backHandler, *highScoreHandler, highscores[newScreenId], newOption);
        else if(newScreenId == ScreenEnum::MINESCREEN)
            screen = new MineScreen(*backHandler, *highScoreHandler, highscores[newScreenId], newOption);
        else if(newScreenId == ScreenEnum::TICSCREEN)
            screen = new TicScreen(*backHandler, *highScoreHandler, highscores[newScreenId], newOption);
        else if(newScreenId == ScreenEnum::PA2SCREEN)
            screen = new PixelAdventureScreen(*backHandler, *highScoreHandler, highscores[newScreenId], newOption);
        else if(newScreenId == ScreenEnum::SETTINGSSCREEN)
            screen = new SettingsScreen(*backHandler, *highScoreHandler, highscores[newScreenId], newOption);
        else if(newScreenId == ScreenEnum::ABOUTSCREEN)
            screen = new AboutScreen(*backHandler, *highScoreHandler, highscores[newScreenId], newOption);
        else
            printf("[Main] Something failed badly\n");
    } else if(screen->screenId == ScreenEnum::SPLASHSCREEN) {
        delete screen;
        screen = new MenuScreen(*backHandler, *highScoreHandler, newScreenId, newOption);
    } else {
        delete screen;
        screen = new MenuScreen(*backHandler, *highScoreHandler, newScreenId-2, newOption);
    }
    shouldSwitchScreen = false;
}

int main(int argc, char *argv[]) {
    sleep_ms(50);
    vreg_set_voltage(VREG_VOLTAGE_1_20);
    sleep_ms(1);
    set_sys_clock_khz(266 * 1000, true);
    sleep_ms(50);

    stdio_init_all();
    sleep_ms(1000);

    printf("[Main] Starting\n");
    srand((unsigned int)time(0));
    readHighScoreData();
    Display *display = new Display();
    display->initDMAChannel();
    display->initSequence();
    display->clear(Color(255, 255, 255));
    display->update();

    Battery *battery = new Battery();
    KeyBoard *keyboard = new KeyBoard();
    screen = new SplashScreen(*backHandler, *highScoreHandler, 0, 1);

    timetype lastUpdate = getTime();
    bool close = false;
    while (!close) {
        uint16_t deltaTimeMS = getTimeDiffMS(lastUpdate);
        lastUpdate = getTime();

        screen->update(deltaTimeMS);
        keyboard->checkKeyState(screen);
        screen->draw(display);

        battery->drawLevel(display);
        // printf("[Main] FPS: %d\n", int(1000 / deltaTimeMS));
        display->update();
        checkScreenSwitch();
    }

    return EXIT_SUCCESS;
}

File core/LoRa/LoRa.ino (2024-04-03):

#include "lora.h"
#include <SPI.h>

#define LED_GPIO PIN_LED
Lora *lora;

void setup() {
  pinMode(LED_GPIO, OUTPUT);
  Serial.begin(9600);
  delay(2000);
  Serial.println("[Main] Setting up Lora Chip");
  SPI.begin();
  
  lora = new Lora();
  lora->SetRxEnable();
  Serial.println("[Main] Done");
}

void loop() {
  digitalWrite(LED_GPIO, LOW);

  char payload[] = "Hi Lora, GameTiger";
  lora->SendData(22, payload, strlen(payload));
  uint16_t delta = 0;
  do {
      delta += 50;
      delay(50);
      lora->ProcessIrq();
  } while(delta <= 5000);

  lora->CheckDeviceStatus();

  digitalWrite(LED_GPIO, HIGH);
  delay(2000);
}

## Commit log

2024-04-03 Repo reset
    [503398-1892.step, B3FS-4052P--3DModel-STEP-273799.STEP, GT-USB-7010ASV.blend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]
2024-08-17 Upgraded SDK version, added acrylic case
    [GameTiger.kicad_pcb, GameTiger.kicad_sch]
2024-08-18 Fixed issue with new SDK version and removed SDL implementation
    [battery.cpp, keyboard.cpp, main.cpp]
